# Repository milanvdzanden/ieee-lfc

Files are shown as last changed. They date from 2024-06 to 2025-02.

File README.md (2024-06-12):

# IEEE Line Follower Competition
This repository will serve as the main source of all technical details related to the Line Follower Competition. This repository also contains all design files for the robot template kit, which will be made available for purchase as well. Some example code will be provided but you are completely free to change these design files, code and even the robot to get an edge over the other teams.

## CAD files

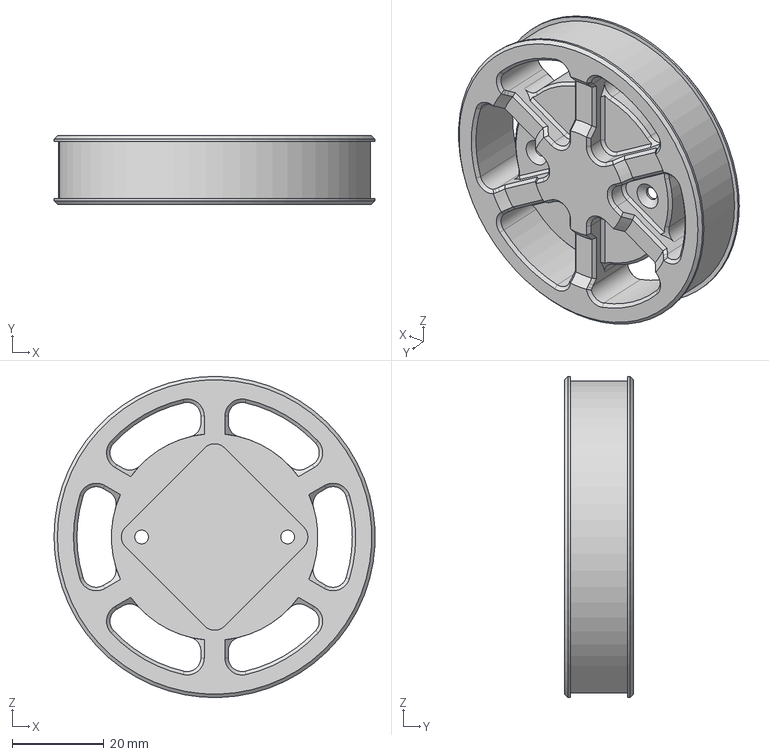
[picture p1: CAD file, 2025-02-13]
CadModels/Wheel.step
70.0 x 15.0 x 70.0 mm

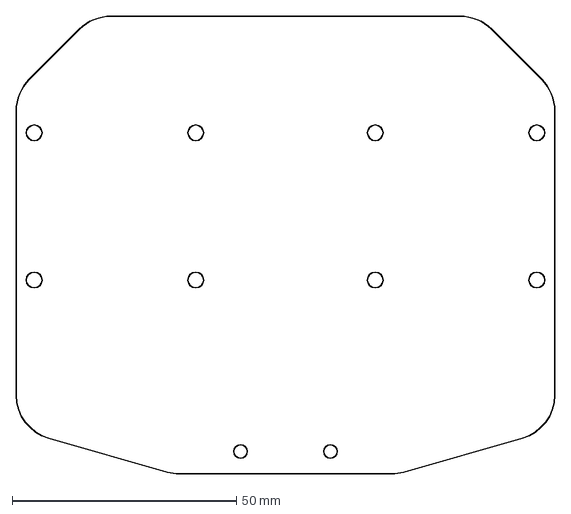
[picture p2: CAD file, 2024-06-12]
MainBoardV3/Contours.dxf
120.0 x 102.0 mm

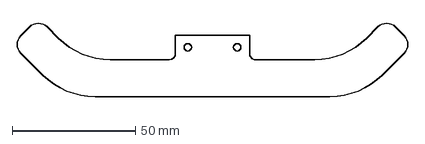
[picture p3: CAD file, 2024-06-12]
SensorBoardV2/Outline.dxf
159.3 x 29.7 mm

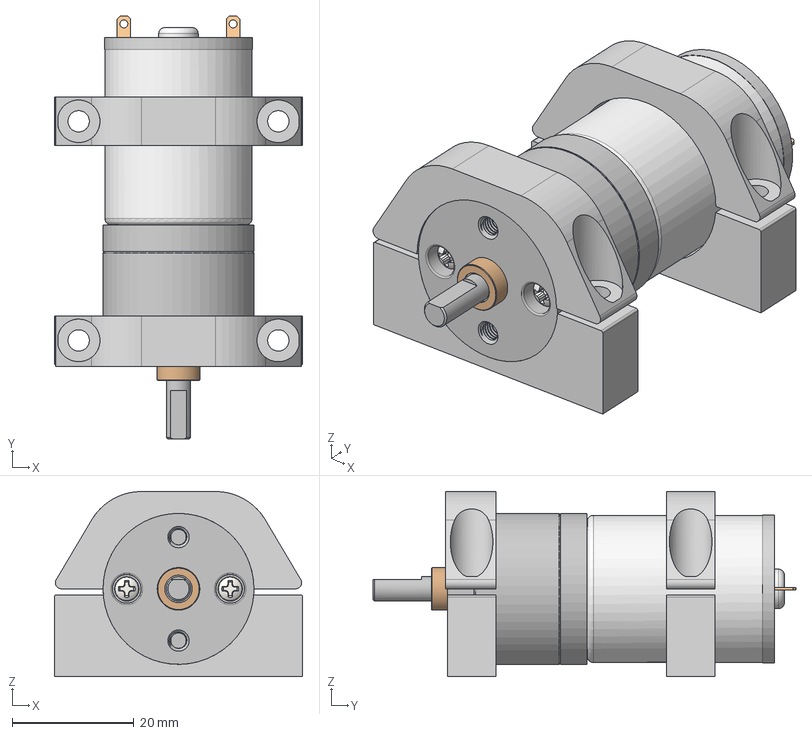
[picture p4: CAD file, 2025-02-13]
CadModels/MotorMount.step
40.8 x 69.5 x 30.4 mm
Motor
Gearbox
90116A027_316 Stainless Steel Pan Head Phillips Screws x 2

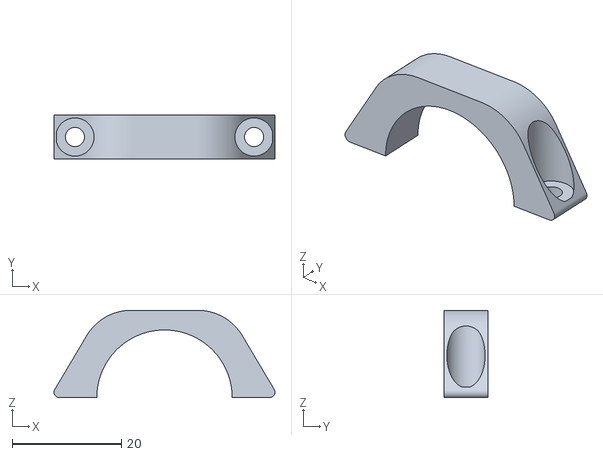
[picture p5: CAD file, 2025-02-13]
CadModels/MotorMountTop.stl
40.5 x 8.00 x 16.0

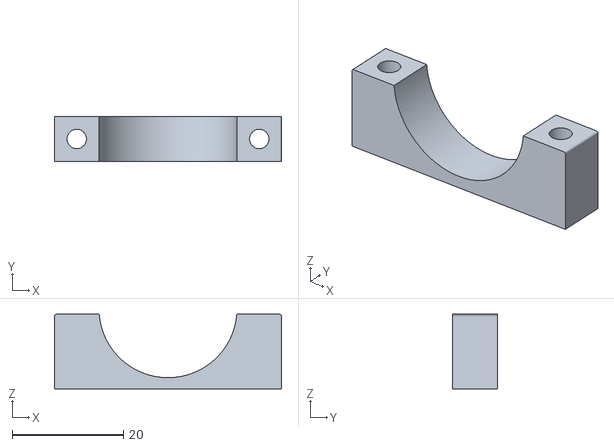
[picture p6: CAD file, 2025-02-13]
CadModels/MotorMountBottom.stl
40.8 x 8.00 x 13.4

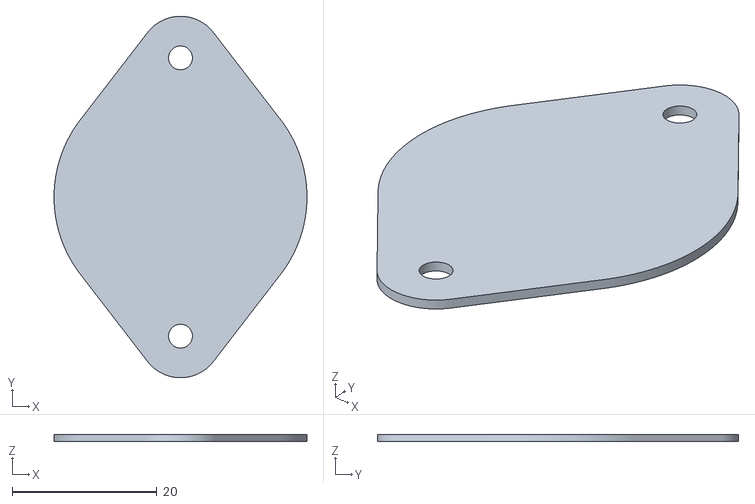
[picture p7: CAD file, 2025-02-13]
CadModels/BallCap.stl
35.0 x 50.0 x 1.00

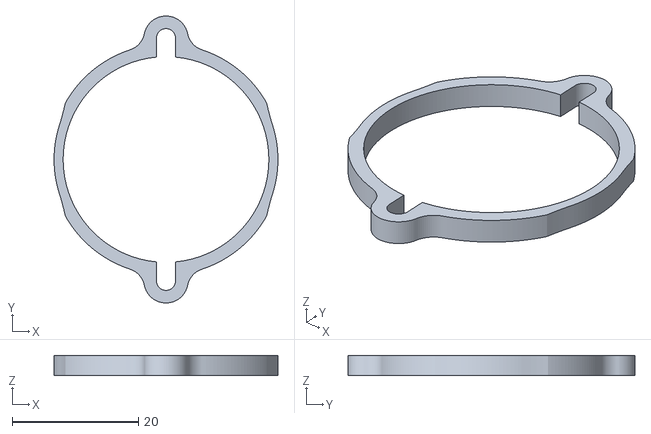
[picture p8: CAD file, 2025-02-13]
CadModels/BallSpacer.stl
35.5 x 45.5 x 3.20

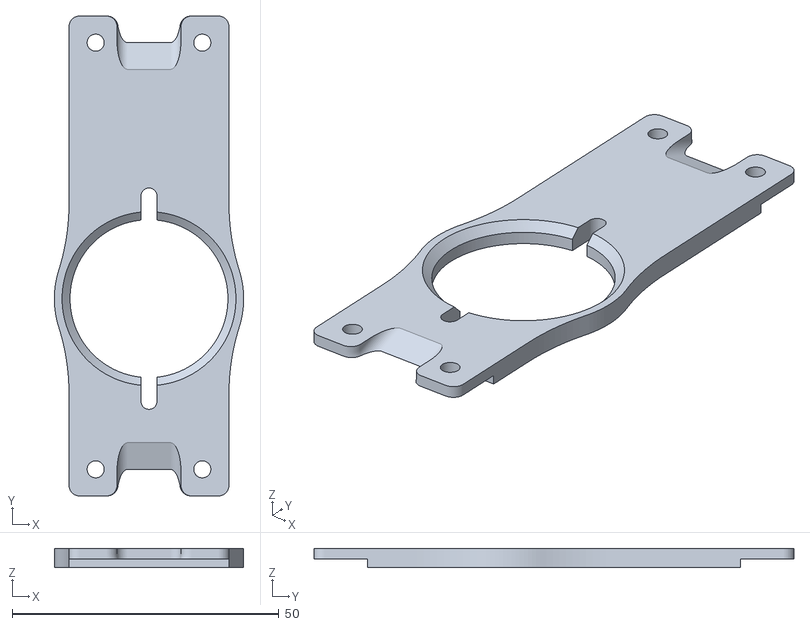
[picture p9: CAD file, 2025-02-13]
CadModels/SensorBridge.stl
35.5 x 90.0 x 3.60

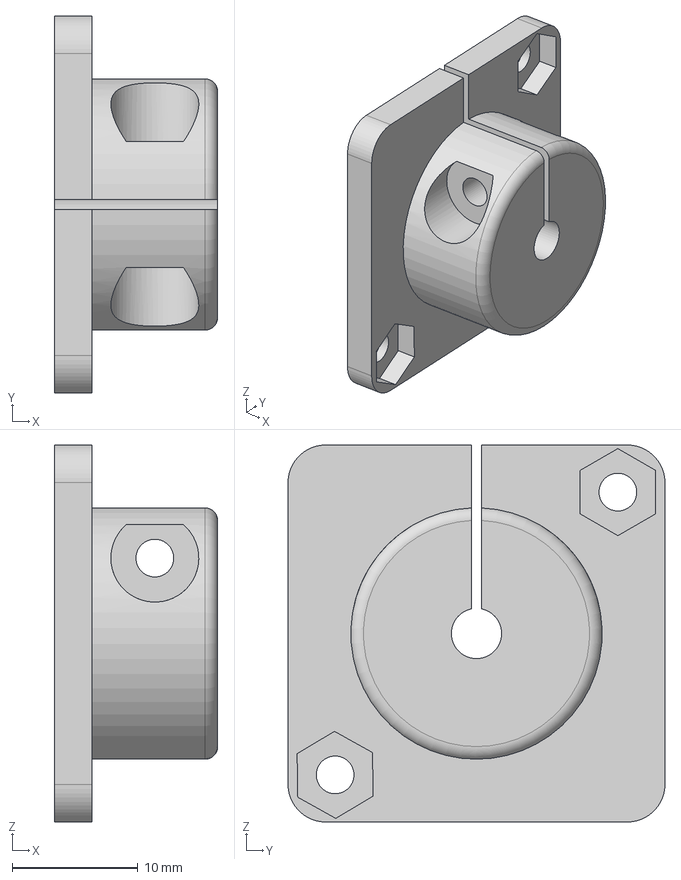
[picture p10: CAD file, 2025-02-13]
CadModels/WheelHub.step
13.0 x 30.0 x 30.0 mm

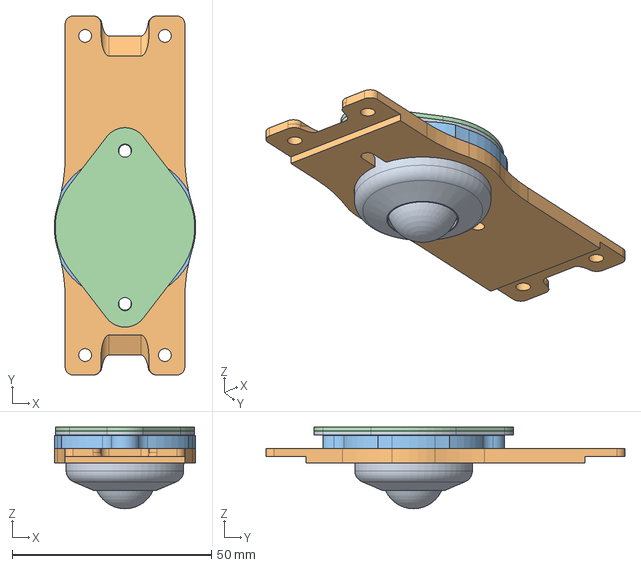
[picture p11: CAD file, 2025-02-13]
CadModels/SensorMount.step
35.4 x 90.0 x 20.4 mm

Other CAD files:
CadModels/Wheel.stl
CadModels/WheelHub.stl

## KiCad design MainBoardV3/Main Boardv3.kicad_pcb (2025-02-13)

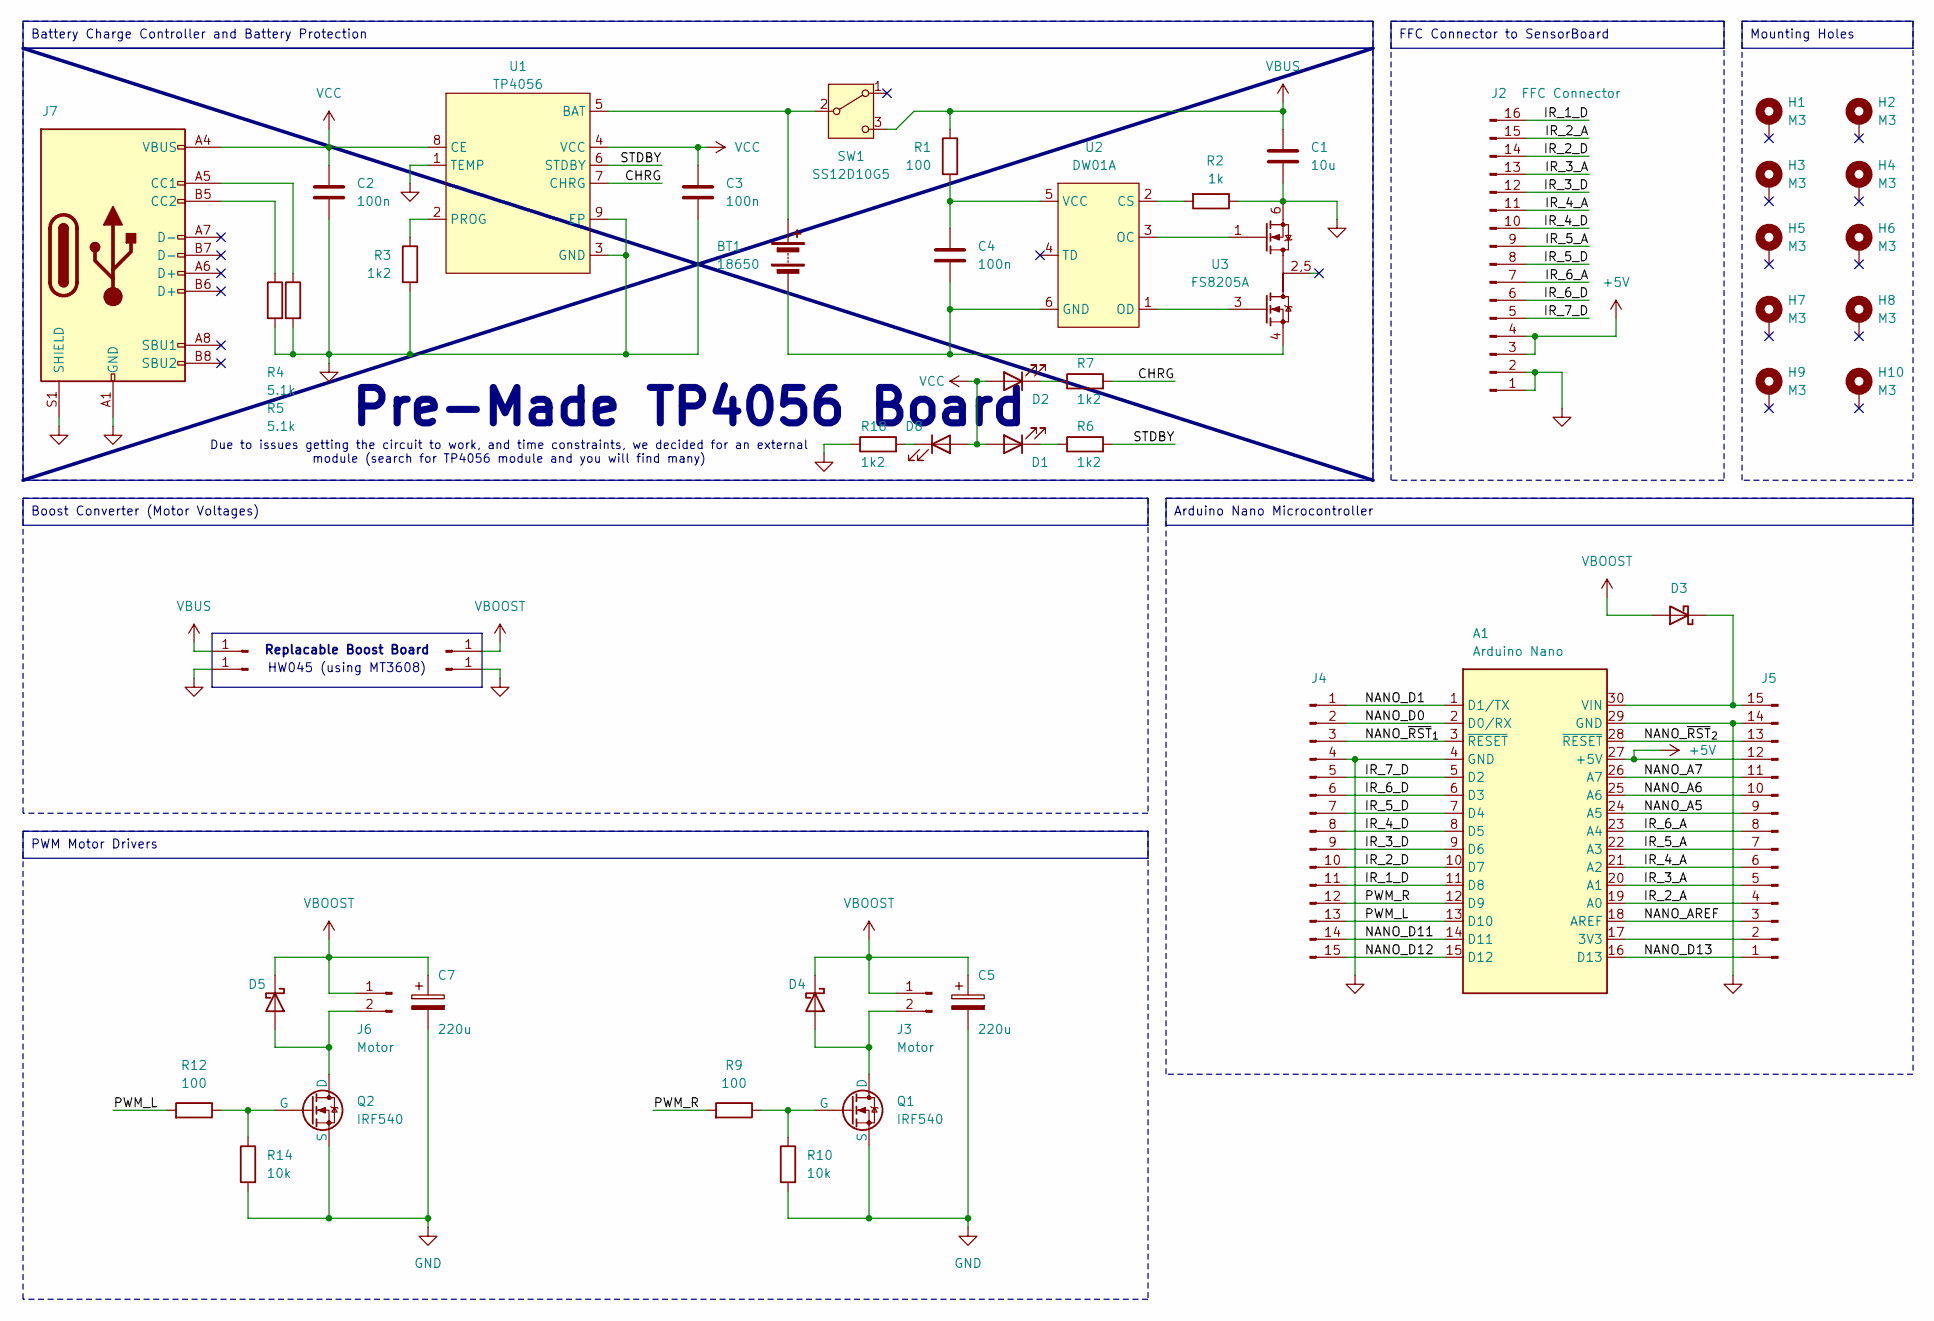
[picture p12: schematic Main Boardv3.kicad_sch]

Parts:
A1: Arduino Nano; Arduino_Nano
BT1: 18650; BatteryHolder_Keystone_1042_1x18650
C1: 10u; C_0603_1608Metric
C2, C3, C4: 100n; C_0603_1608Metric
C5, C7: 220u; CP_Radial_D8.0mm_P5.00mm
D1, D2, D8: LED; LED_0603_1608Metric
D3, D4, D5: D_Schottky; D_SMA
H1, H2, H3, H4, H5, H6, H7, H8, H9, H10: M3; MountingHole_Soldernut_M3
J2: FFC Connector; Hirose_FH12-16S-0.5SH_1x16-1MP_P0.50mm_Horizontal
J3, J6: Motor; TerminalBlock_bornier-2_P5.08mm
J4, J5: Row 2; PinSocket_1x15_P2.54mm_Vertical
J7: USB_C_Receptacle_USB2.0_16P; USB_C_Receptacle_GCT_USB4105-xx-A_16P_TopMnt_Horizontal
J101, J102, J103, J104: Conn_01x01_Pin; PinHeader_1x01_P2.54mm_Vertical
Q1, Q2: IRF540; TO-220F-3_Vertical
R1, R9, R12: 100; R_0603_1608Metric
R2: 1k; R_0603_1608Metric
R3, R6, R7, R18: 1k2; R_0603_1608Metric
R4, R5: 5.1k; R_0603_1608Metric
R10, R14: 10k; R_0603_1608Metric
SW1: SS12D10G5; SS12D10G5_SlideSwitch
U1: TP4056; Infineon_PG-DSO-8-27_3.9x4.9mm_EP2.65x3mm
U2: DW01A; SOT-23-6
U3: FS8205A; SOT-23-6

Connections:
+5V: A1.27 (+5V), J2.3, J2.4, J5.12
/CHRG: R7.2, U1.7 (CHRG)
/IR_1_D: A1.11 (D8), J2.16, J4.11
/IR_2_A: A1.19 (A0), J2.15, J5.4
/IR_2_D: A1.10 (D7), J2.14, J4.10
/IR_3_A: A1.20 (A1), J2.13, J5.5
/IR_3_D: A1.9 (D6), J2.12, J4.9
/IR_4_A: A1.21 (A2), J2.11, J5.6
/IR_4_D: A1.8 (D5), J2.10, J4.8
/IR_5_A: A1.22 (A3), J2.9, J5.7
/IR_5_D: A1.7 (D4), J2.8, J4.7
/IR_6_A: A1.23 (A4), J2.7, J5.8
/IR_6_D: A1.6 (D3), J2.6, J4.6
/IR_7_D: A1.5 (D2), J2.5, J4.5
/NANO_A5: A1.24 (A5), J5.9
/NANO_A6: A1.25 (A6), J5.10
/NANO_A7: A1.26 (A7), J5.11
/NANO_AREF: A1.18 (AREF), J5.3
/NANO_D0: A1.2 (D0/RX), J4.2
/NANO_D1: A1.1 (D1/TX), J4.1
/NANO_D11: A1.14 (D11), J4.14
/NANO_D12: A1.15 (D12), J4.15
/NANO_D13: A1.16 (D13), J5.1
/NANO_~RST_{1}: A1.3 (~RESET), J4.3
/NANO_~RST_{2}: A1.28 (~RESET), J5.13
/PWM_L: A1.13 (D10), J4.13, R12.2
/PWM_R: A1.12 (D9), J4.12, R9.2
/STDBY: R6.2, U1.6 (STDBY)
GND: A1.4 (GND), A1.29 (GND), C1.2, C2.2, C3.2, C5.2, C7.2, J2.1, J2.2, J4.4, J5.14, J7.A1 (GND), J7.A12 (GND), J7.B1 (GND), J7.B12 (GND), J7.S1 (SHIELD), J102.1, J104.1, Q1.3 (S), Q2.3 (S), R2.1, R3.2, R4.2, R5.2, R10.2, R14.2, R18.1, U1.1 (TEMP), U1.3 (GND), U1.9 (EP), U3.6
unnamed: A1.17 (3V3), J5.2
unnamed: A1.30 (VIN), D3.1 (K), J5.15
unnamed: BT1.1 (+), SW1.2 (B), U1.5 (BAT)
unnamed: BT1.2 (-), C4.2, U2.6 (GND), U3.4
unnamed: D1.1 (K), R6.1
unnamed: D2.1 (K), R7.1
unnamed: D4.2 (A), J3.2, Q1.2 (D)
unnamed: D5.2 (A), J6.2, Q2.2 (D)
unnamed: D8.1 (K), R18.2
unnamed: J7.A5 (CC1), R5.1
unnamed: J7.B5 (CC2), R4.1
unnamed: Q1.1 (G), R9.1, R10.1
unnamed: Q2.1 (G), R12.1, R14.1
unnamed: R3.1, U1.2 (PROG)
unnamed: R2.2, U2.2 (CS)
unnamed: U2.3 (OC), U3.1
unnamed: U2.1 (OD), U3.3
unnamed: C4.1, R1.2, U2.5 (VCC)
VBOOST: C5.1, C7.1, D3.2 (A), D4.1 (K), D5.1 (K), J3.1, J6.1, J103.1
VBUS: C1.1, J101.1, R1.1, SW1.3 (C)
VCC: C2.1, C3.1, D1.2 (A), D2.2 (A), D8.2 (A), J7.A4 (VBUS), J7.A9 (VBUS), J7.B4 (VBUS), J7.B9 (VBUS), U1.4 (VCC), U1.8 (CE)

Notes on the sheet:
Mounting Holes
Arduino Nano Microcontroller
Battery Charge Controller and Battery Protection
FFC Connector to SensorBoard
Boost Converter (Motor Voltages)
PWM Motor Drivers
HW045 (using MT3608)
Replacable Boost Board
Due to issues getting the circuit to work, and time constraints, we decided for an external module (search for TP4056 module and you will find many)
Pre-Made TP4056 Board

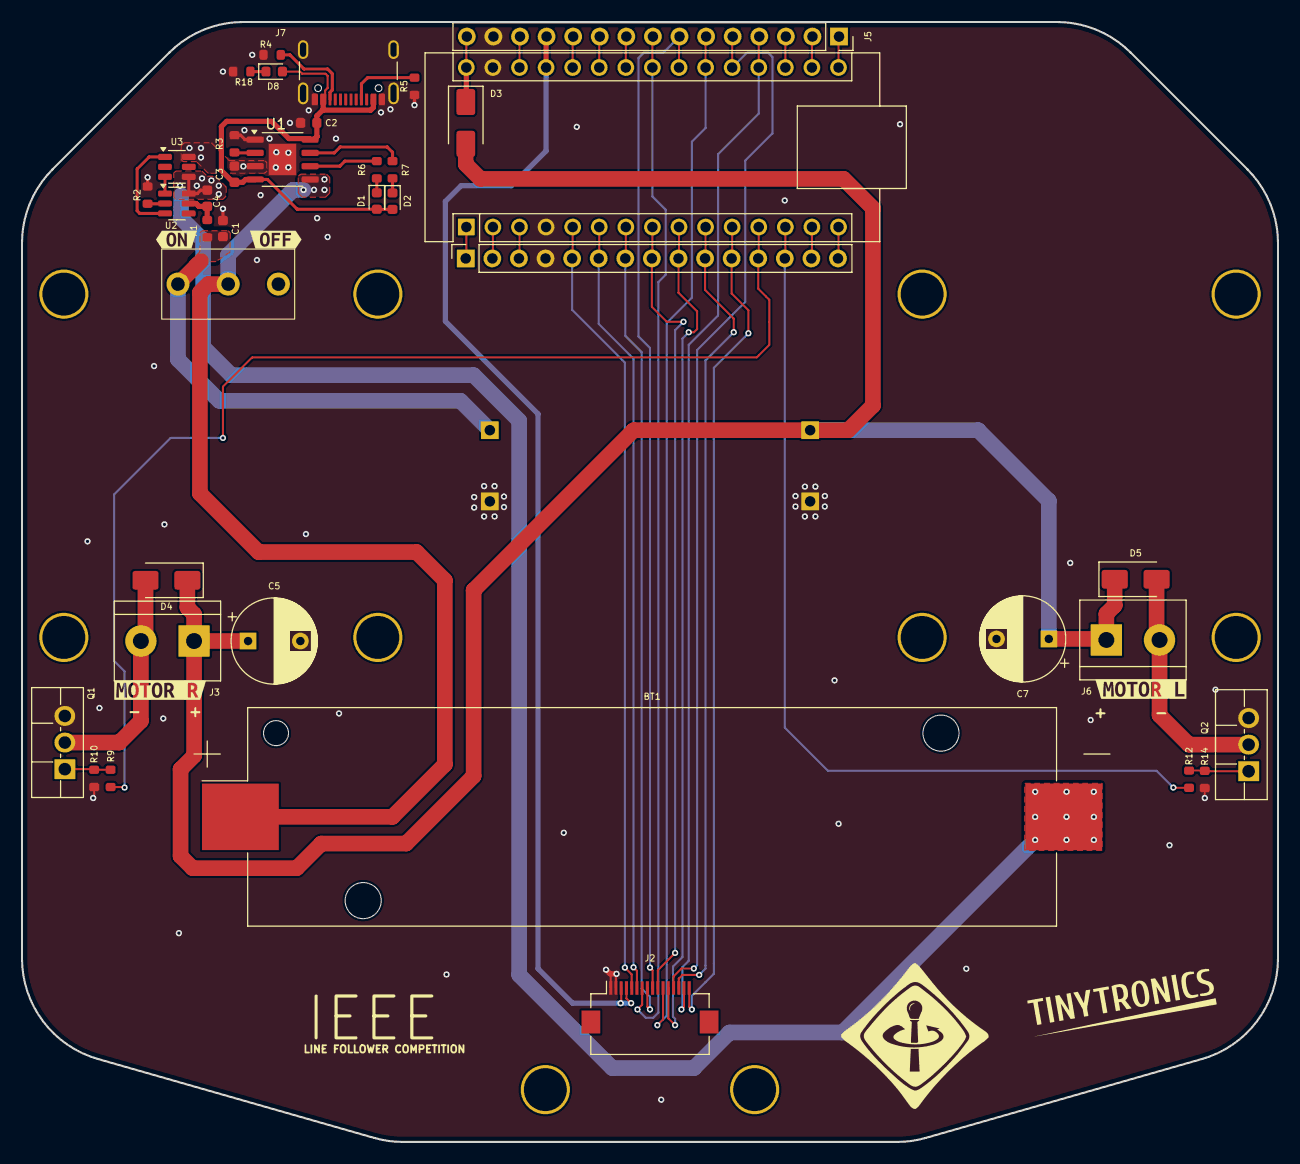
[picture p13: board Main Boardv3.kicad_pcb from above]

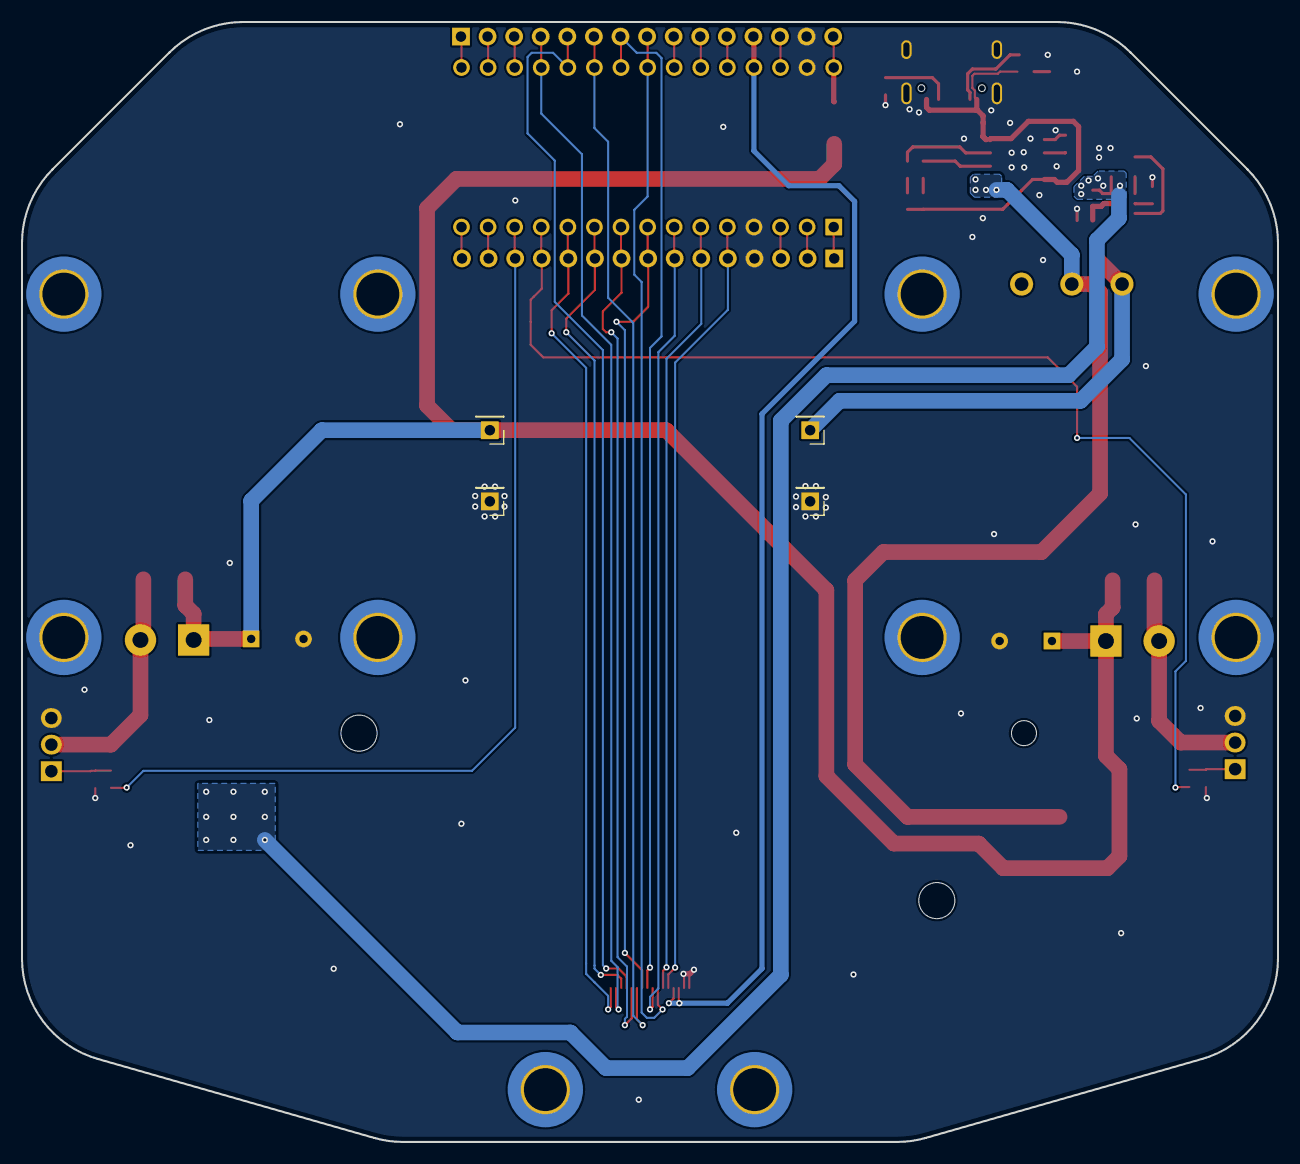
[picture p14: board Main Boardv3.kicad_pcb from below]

Board: 2 copper layers, 120.0 x 107.0 mm, 56 parts (14 on the bottom side), 50 nets.

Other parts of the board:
kibuzzard-666C7E6A: G***; kibuzzard-666C7E6A
kibuzzard-666C7E77: G***; kibuzzard-666C7E77
kibuzzard-666C76A4: G***; kibuzzard-666C76A4
kibuzzard-666C76B2: G***; kibuzzard-666C76B2

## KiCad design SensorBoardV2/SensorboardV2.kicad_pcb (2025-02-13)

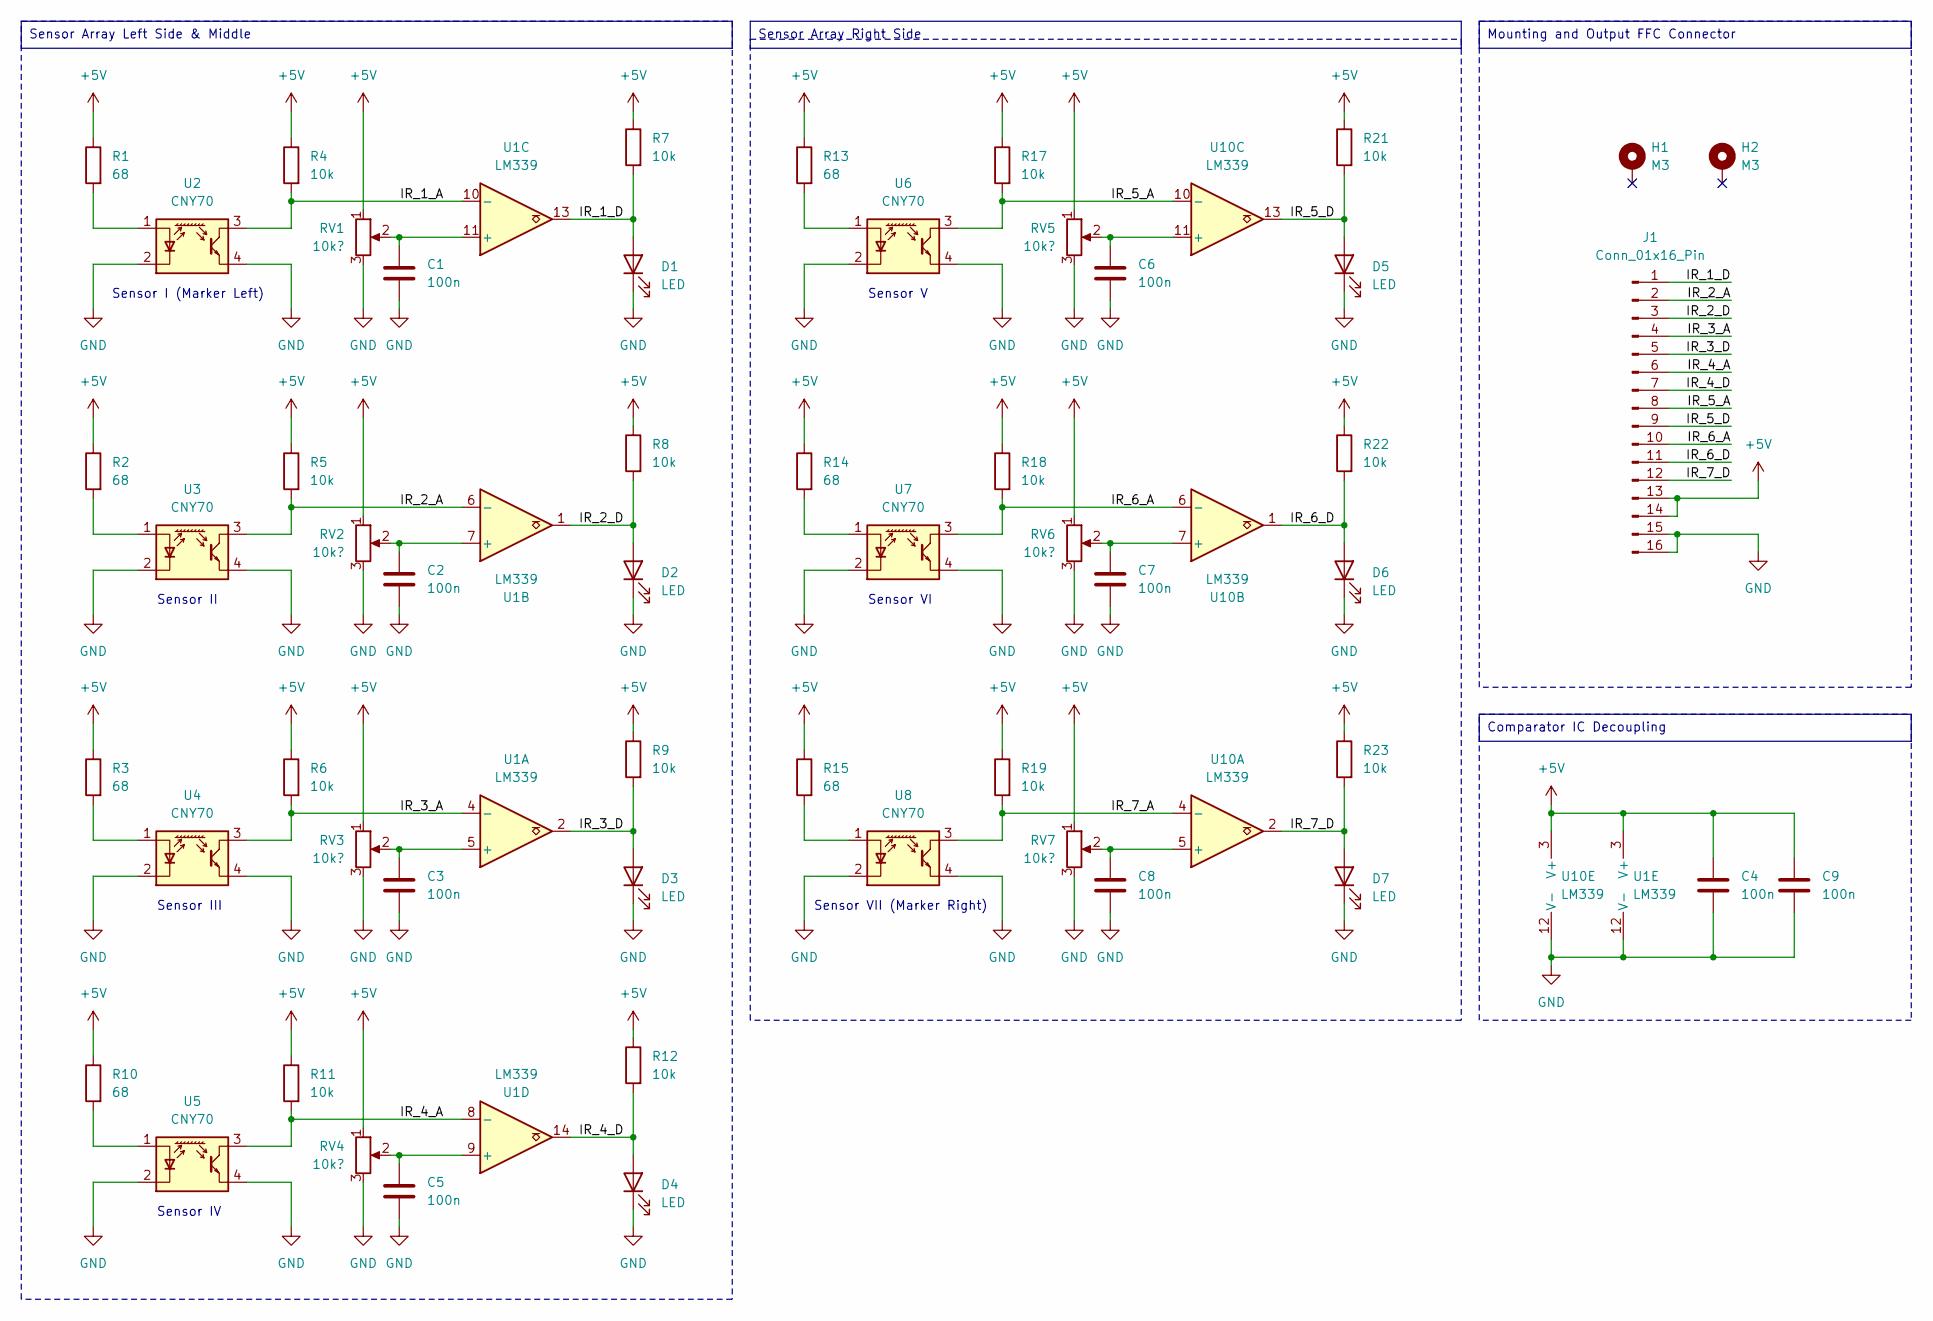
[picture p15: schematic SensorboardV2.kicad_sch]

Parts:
C1, C2, C3, C4, C5, C6, C7, C8, C9: 100n; C_0603_1608Metric
D1, D2, D3, D4, D5, D6, D7: LED; D_0603_1608Metric
H1, H2: M3; MountingHole_Soldernut_M3
J1: Conn_01x16_Pin; Hirose_FH12-16S-0.5SH_1x16-1MP_P0.50mm_Horizontal
R1, R2, R3, R10, R13, R14, R15: 68; R_0603_1608Metric
R4, R5, R6, R7, R8, R9, R11, R12, R17, R18, R19, R21, R22, R23: 10k; R_0603_1608Metric
RV1, RV2, RV3, RV4, RV5, RV6, RV7: 10k?; 3362P1222LF
U1, U10: LM339; SO-14_3.9x8.65mm_P1.27mm
U2, U3, U4, U5, U6, U7, U8: CNY70; Vishay_CNY70

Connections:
+5V: C4.1, C9.1, J1.13, J1.14, R1.1, R2.1, R3.1, R4.1, R5.1, R6.1, R7.1, R8.1, R9.1, R10.1, R11.1, R12.1, R13.1, R14.1, R15.1, R17.1, R18.1, R19.1, R21.1, R22.1, R23.1, RV1.1, RV2.1, RV3.1, RV4.1, RV5.1, RV6.1, RV7.1, U1.3 (V+), U10.3 (V+)
/IR_1_A: R4.2, U1.10 (-), U2.3 (C)
/IR_1_D: D1.2 (A), J1.1, R7.2, U1.13
/IR_2_A: J1.2, R5.2, U1.6 (-), U3.3 (C)
/IR_2_D: D2.2 (A), J1.3, R8.2, U1.1
/IR_3_A: J1.4, R6.2, U1.4 (-), U4.3 (C)
/IR_3_D: D3.2 (A), J1.5, R9.2, U1.2
/IR_4_A: J1.6, R11.2, U1.8 (-), U5.3 (C)
/IR_4_D: D4.2 (A), J1.7, R12.2, U1.14
/IR_5_A: J1.8, R17.2, U6.3 (C), U10.10 (-)
/IR_5_D: D5.2 (A), J1.9, R21.2, U10.13
/IR_6_A: J1.10, R18.2, U7.3 (C), U10.6 (-)
/IR_6_D: D6.2 (A), J1.11, R22.2, U10.1
/IR_7_A: R19.2, U8.3 (C), U10.4 (-)
/IR_7_D: D7.2 (A), J1.12, R23.2, U10.2
GND: C1.2, C2.2, C3.2, C4.2, C5.2, C6.2, C7.2, C8.2, C9.2, D1.1 (K), D2.1 (K), D3.1 (K), D4.1 (K), D5.1 (K), D6.1 (K), D7.1 (K), J1.15, J1.16, RV1.3, RV2.3, RV3.3, RV4.3, RV5.3, RV6.3, RV7.3, U1.12 (V-), U2.2 (K), U2.4 (E), U3.2 (K), U3.4 (E), U4.2 (K), U4.4 (E), U5.2 (K), U5.4 (E), U6.2 (K), U6.4 (E), U7.2 (K), U7.4 (E), U8.2 (K), U8.4 (E), U10.12 (V-)
unnamed: C3.1, RV3.2, U1.5 (+)
unnamed: C2.1, RV2.2, U1.7 (+)
unnamed: C1.1, RV1.2, U1.11 (+)
unnamed: C5.1, RV4.2, U1.9 (+)
unnamed: R1.2, U2.1 (A)
unnamed: R2.2, U3.1 (A)
unnamed: R3.2, U4.1 (A)
unnamed: R10.2, U5.1 (A)
unnamed: R13.2, U6.1 (A)
unnamed: R14.2, U7.1 (A)
unnamed: R15.2, U8.1 (A)
unnamed: C8.1, RV7.2, U10.5 (+)
unnamed: C7.1, RV6.2, U10.7 (+)
unnamed: C6.1, RV5.2, U10.11 (+)

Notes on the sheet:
Mounting and Output FFC Connector
Sensor Array Right Side
Sensor Array Left Side & Middle
Comparator IC Decoupling
Sensor VI
Sensor II
Sensor III
Sensor V
Sensor IV
Sensor I (Marker Left)
Sensor VII (Marker Right)

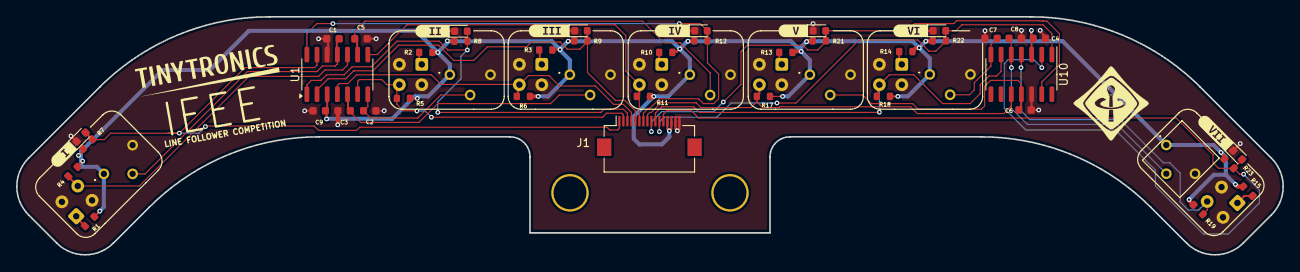
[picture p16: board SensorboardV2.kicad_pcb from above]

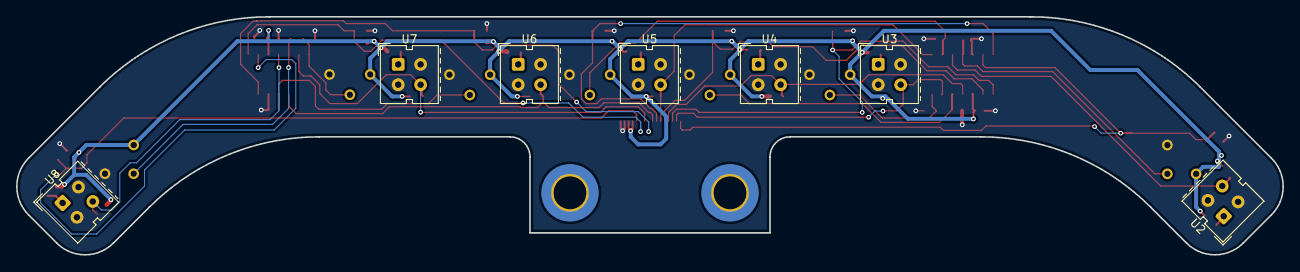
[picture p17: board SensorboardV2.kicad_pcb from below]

Board: 2 copper layers, 158.3 x 29.7 mm, 63 parts (9 on the bottom side), 30 nets.

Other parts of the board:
kibuzzard-6662E8B3: G***; kibuzzard-6662E8B3
kibuzzard-6662EBB8: G***; kibuzzard-6662EBB8
kibuzzard-6662EBDC: G***; kibuzzard-6662EBDC
kibuzzard-6662EBE3: G***; kibuzzard-6662EBE3
kibuzzard-6662EBED: G***; kibuzzard-6662EBED
kibuzzard-6662ED8C: G***; kibuzzard-6662ED8C
kibuzzard-6662ED27: G***; kibuzzard-6662ED27

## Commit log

2024-06-12 Up to date files
    [Sensorboard_V1.kicad_pcb, Sensorboard_V1.kicad_sch]
2024-06-12 Renamed some files
    [Sensorboard.kicad_pcb, Sensorboard.kicad_sch]
2024-06-12 Cleaned up MainBoard Schematic
    [Main Board.kicad_sch]
2024-06-12 Small Changes to mainboard schematic
    [Main Board.kicad_pcb, Main Board.kicad_sch]
2024-06-12 SensorBoard Updates
    [Sensorboard.kicad_sch]
2024-06-12 Updated Mainboard
    [Main Board.kicad_pcb, Main Board.kicad_sch]
2024-06-12 Main board pcb traced
    [Main Board.kicad_pcb, Main Board.kicad_sch]
2024-06-12 Updated Version
    [Main Board.kicad_pcb]
2024-06-14 progressed on main board
    Made some more connections. Not fully finished it, but added it for completeness
    [Main Board.kicad_pcb]
2024-06-14 Finished MainBoard
    [Main Board.kicad_pcb, Main Board.kicad_sch]
2024-06-14 Removed unneccesary filed
    [Main Board.kicad_pcb]
2024-06-14 Pinout Update
    [Main Board.kicad_pcb, Main Board.kicad_sch, Sensorboard.kicad_pcb]
2024-11-17 Created SensorboardV2
    [Outline.dxf, SensorboardV2.kicad_pcb, SensorboardV2.kicad_sch]
2024-11-23 Added boost board, updated schematic
    [BoostBoard.kicad_pcb, BoostBoard.kicad_sch, Contours.dxf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]
2024-11-28 Uploaded Cad Models and recent PCB
    [BoostBoard.kicad_pcb, BoostBoard.kicad_sch, BoostBoard.step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]
2025-02-13 Final Update
    [BallCap.stl, BallSpacer.stl, BoostBoard.kicad_pcb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]
